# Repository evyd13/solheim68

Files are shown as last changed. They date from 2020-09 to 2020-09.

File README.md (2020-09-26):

# Solheim68

Solheim68 PCB
This PCB is a direct replacement designed for the VA68M (Mini-USB) from Varmilo. Use this PCB as you wish, the license allows commercial use.  
Unfortunately it was impossible to support PCB mounted stabilizers on this one.

## Features
- Compatible with QMK Firmware
- More layout support (only with custom plate)

## Supported layouts
Supported layouts of the Solheim68

## Building
If you feel like building a few of these PCBs yourself, go to the 'Releases' tab and download the latest gerber files. Order those at your favourite PCB manufacturer, get the components needed (see below) and solder them on! A hot air station is not required but a soldering iron is. Flux is recommended.

## Opening the project
To open the files you will need the latest KiCAD nightly version.

## Bill of materials (BOM)
Amount is per PCB, multiply as needed.

| LCSC part # | Description | Value | Package  | Amount |
| --- | --- | ----- | --- | ---:|
| C128353 | Capacitor | 0.1uF | 0805 | 4 |
| C131056 | Capacitor | 4.7uF | 0805 | 1 |
| C215803 | Capacitor | 1uF | 0805 | 1 |
| C109001 | Diode | | 0805 | 72 |
| C145778 | USB Connector | | SMD/THT  | 1 |
| C103904 | Resistor | 10K | 0805 | 2 |
| C325772 | Resistor | 22 | 0805 | 2 |
| C44854 | MCU | 32U4  | QFP-44 | 1 |
| C341521 | Resonator | 16MHz | SMD | 1 |
| C92584 | Switch | | SMD | 1 |

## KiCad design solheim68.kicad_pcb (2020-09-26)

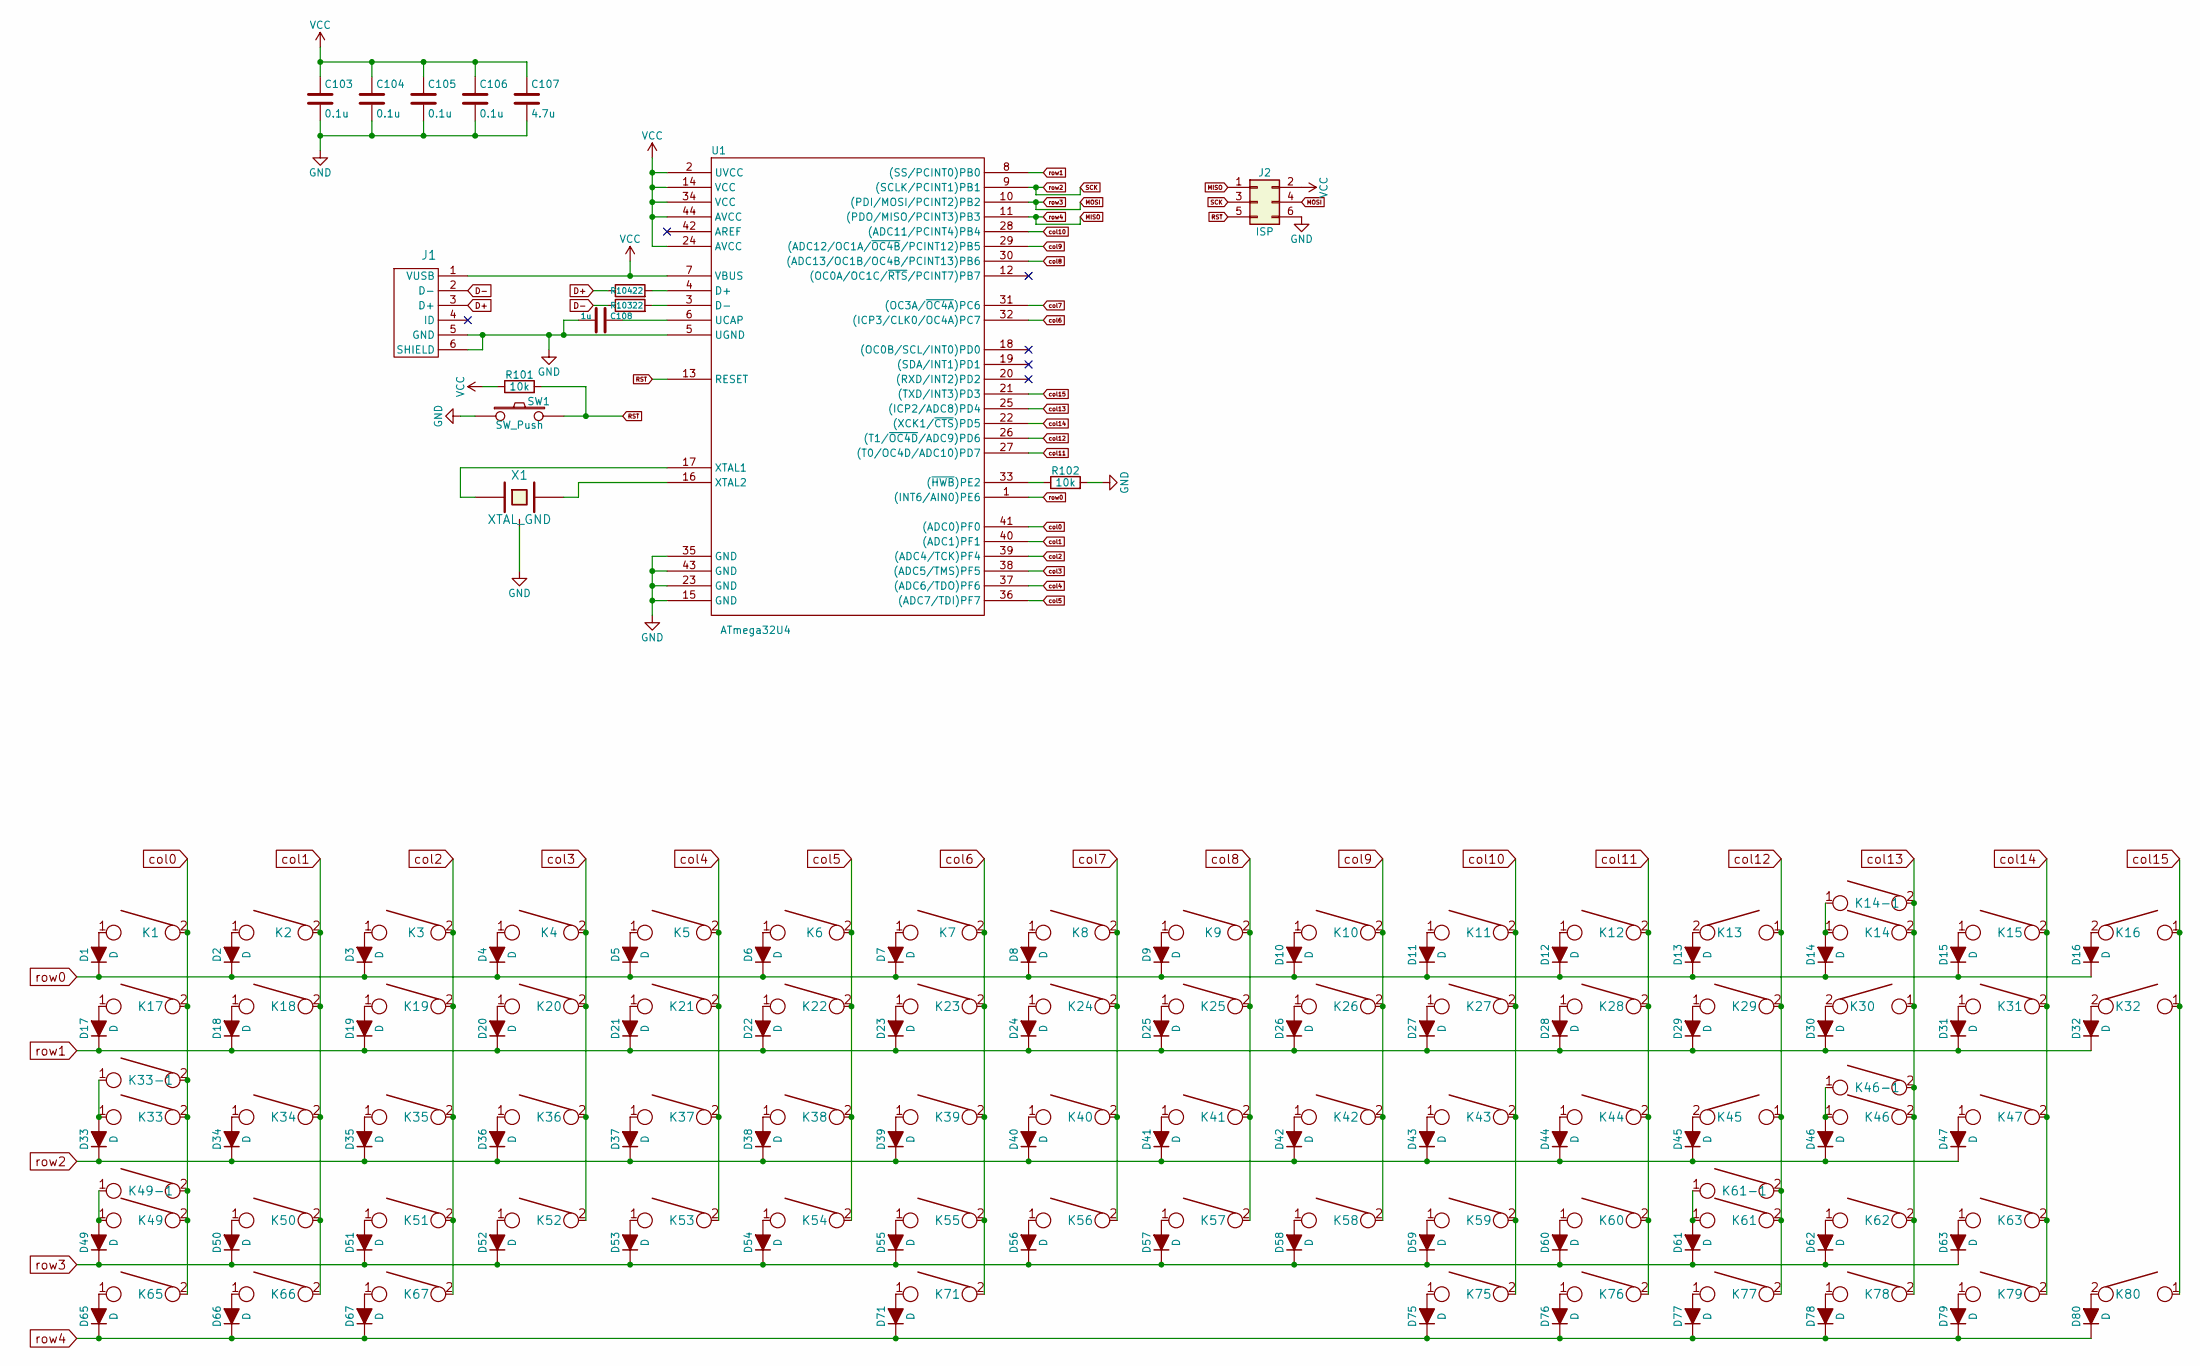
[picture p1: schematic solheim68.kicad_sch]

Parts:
C103, C104, C105, C106: 0.1u; C_0805
C107: 4.7u; C_0805
C108: 1u; C_0805
D1, D2, D3, D4, D5, D6, D7, D8, D9, D10, D11, D12, D13, D14, D15, D16, D17, D18, D19, D20, D21, D22, D23, D24, D25, D26, D27, D28, D29, D30, D31, D32, D33, D34, D35, D36, D37, D38, D39, D40, D41, D42, D43, D44, D45, D46, D47, D49, D50, D51, D52, D53, D54, D55, D56, D57, D58, D59, D60, D61, D62, D63, D65, D66, D67, D71, D75, D76, D77, D78, D79, D80: D; D_0805
J1: USB_mini_micro_B; U-M-M5DD-W-1
J2: ISP; isp_standard
K1, K2, K3, K4, K5, K6, K7, K8, K9, K10, K11, K12, K13, K14-1, K15, K16, K18, K19, K20, K21, K22, K23, K24, K25, K26, K27, K28, K29, K31, K32, K34, K35, K36, K37, K38, K39, K40, K41, K42, K43, K44, K45, K47, K50, K51, K52, K53, K54, K55, K56, K57, K58, K59, K60, K62, K63, K78, K79, K80: KEYSW; CHERRY_PLATE_100H
K14: KEYSW; CHERRY_PLATE_200H
K17, K30: KEYSW; CHERRY_PLATE_150H
K33, K61-1: KEYSW; CHERRY_PLATE_175H
K33-1, K49-1, K65, K66, K67, K75, K76, K77: KEYSW; CHERRY_PLATE_125H
K46, K49: KEYSW; CHERRY_PLATE_225H
K46-1: KEYSW; CHERRY_PLATE_200H_V
K61: KEYSW; CHERRY_PLATE_275H
K71: KEYSW; CHERRY_PLATE_625H
R101, R102: 10k; R_0805
R103, R104: 22; R_0805
SW1: SW_Push; SW_SPST_TL3342
U1: ATmega32U4; ATMEGA32U4
X1: XTAL_GND; Resonator_SMD_muRata_CSTNExxV-3Pin-p1.2

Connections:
D+: J1.3 (D+), R104.1
D-: J1.2 (D-), R103.1
GND: C103.2, C104.2, C105.2, C106.2, C107.2, C108.2, J1.5 (GND), J1.6 (SHIELD), J2.6, R102.2, SW1.1, U1.5 (UGND), U1.15 (GND), U1.23 (GND), U1.35 (GND), U1.43 (GND), X1.3
MISO: D65.1 (K), D66.1 (K), D67.1 (K), D71.1 (K), D75.1 (K), D76.1 (K), D77.1 (K), D78.1 (K), D79.1 (K), D80.1 (K), J2.1, U1.11 ((PDO/MISO/PCINT3)PB3)
MOSI: D49.1 (K), D50.1 (K), D51.1 (K), D52.1 (K), D53.1 (K), D54.1 (K), D55.1 (K), D56.1 (K), D57.1 (K), D58.1 (K), D59.1 (K), D60.1 (K), D61.1 (K), D62.1 (K), D63.1 (K), J2.4, U1.10 ((PDI/MOSI/PCINT2)PB2)
unnamed: C108.1, U1.6 (UCAP)
unnamed: D1.2 (A), K1.1
unnamed: D2.2 (A), K2.1
unnamed: D3.2 (A), K3.1
unnamed: D4.2 (A), K4.1
unnamed: D5.2 (A), K5.1
unnamed: D6.2 (A), K6.1
unnamed: D7.2 (A), K7.1
unnamed: D8.2 (A), K8.1
unnamed: D9.2 (A), K9.1
unnamed: D10.2 (A), K10.1
unnamed: D11.2 (A), K11.1
unnamed: D12.2 (A), K12.1
unnamed: D13.2 (A), K13.2
unnamed: D14.2 (A), K14.1, K14-1.1
unnamed: D15.2 (A), K15.1
unnamed: D16.2 (A), K16.2
unnamed: D17.2 (A), K17.1
unnamed: D18.2 (A), K18.1
unnamed: D19.2 (A), K19.1
unnamed: D20.2 (A), K20.1
unnamed: D21.2 (A), K21.1
unnamed: D22.2 (A), K22.1
unnamed: D23.2 (A), K23.1
unnamed: D24.2 (A), K24.1
unnamed: D25.2 (A), K25.1
unnamed: D26.2 (A), K26.1
unnamed: D27.2 (A), K27.1
unnamed: D28.2 (A), K28.1
unnamed: D29.2 (A), K29.1
unnamed: D30.2 (A), K30.2
unnamed: D31.2 (A), K31.1
unnamed: D32.2 (A), K32.2
unnamed: D33.2 (A), K33.1, K33-1.1
unnamed: D34.2 (A), K34.1
unnamed: D35.2 (A), K35.1
unnamed: D36.2 (A), K36.1
unnamed: D37.2 (A), K37.1
unnamed: D38.2 (A), K38.1
unnamed: D39.2 (A), K39.1
unnamed: D40.2 (A), K40.1
unnamed: D41.2 (A), K41.1
unnamed: D42.2 (A), K42.1
unnamed: D43.2 (A), K43.1
unnamed: D44.2 (A), K44.1
unnamed: D45.2 (A), K45.2
unnamed: D46.2 (A), K46.1, K46-1.1
unnamed: D47.2 (A), K47.1
unnamed: D49.2 (A), K49.1, K49-1.1
unnamed: D50.2 (A), K50.1
unnamed: D51.2 (A), K51.1
unnamed: D52.2 (A), K52.1
unnamed: D53.2 (A), K53.1
unnamed: D54.2 (A), K54.1
unnamed: D55.2 (A), K55.1
unnamed: D56.2 (A), K56.1
unnamed: D57.2 (A), K57.1
unnamed: D58.2 (A), K58.1
unnamed: D59.2 (A), K59.1
unnamed: D60.2 (A), K60.1
unnamed: D61.2 (A), K61.1, K61-1.1
unnamed: D62.2 (A), K62.1
unnamed: D63.2 (A), K63.1
unnamed: D65.2 (A), K65.1
unnamed: D66.2 (A), K66.1
unnamed: D67.2 (A), K67.1
unnamed: D71.2 (A), K71.1
unnamed: D75.2 (A), K75.1
unnamed: D76.2 (A), K76.1
unnamed: D77.2 (A), K77.1
unnamed: D78.2 (A), K78.1
unnamed: D79.2 (A), K79.1
unnamed: D80.2 (A), K80.2
unnamed: R102.1, U1.33 ((~HWB~)PE2)
unnamed: R103.2, U1.3 (D-)
unnamed: R104.2, U1.4 (D+)
unnamed: U1.16 (XTAL2), X1.2
unnamed: U1.17 (XTAL1), X1.1
RST: J2.5, R101.2, SW1.2, U1.13 (RESET)
SCK: D33.1 (K), D34.1 (K), D35.1 (K), D36.1 (K), D37.1 (K), D38.1 (K), D39.1 (K), D40.1 (K), D41.1 (K), D42.1 (K), D43.1 (K), D44.1 (K), D45.1 (K), D46.1 (K), D47.1 (K), J2.3, U1.9 ((SCLK/PCINT1)PB1)
VCC: C103.1, C104.1, C105.1, C106.1, C107.1, J1.1 (VUSB), J2.2, R101.1, U1.2 (UVCC), U1.7 (VBUS), U1.14 (VCC), U1.24 (AVCC), U1.34 (VCC), U1.44 (AVCC)
col0: K1.2, K17.2, K33.2, K33-1.2, K49.2, K49-1.2, K65.2, U1.41 ((ADC0)PF0)
col1: K2.2, K18.2, K34.2, K50.2, K66.2, U1.40 ((ADC1)PF1)
col2: K3.2, K19.2, K35.2, K51.2, K67.2, U1.39 ((ADC4/TCK)PF4)
col3: K4.2, K20.2, K36.2, K52.2, U1.38 ((ADC5/TMS)PF5)
col4: K5.2, K21.2, K37.2, K53.2, U1.37 ((ADC6/TDO)PF6)
col5: K6.2, K22.2, K38.2, K54.2, U1.36 ((ADC7/TDI)PF7)
col6: K7.2, K23.2, K39.2, K55.2, K71.2, U1.32 ((ICP3/CLK0/OC4A)PC7)
col7: K8.2, K24.2, K40.2, K56.2, U1.31 ((OC3A/~OC4A~)PC6)
col8: K9.2, K25.2, K41.2, K57.2, U1.30 ((ADC13/OC1B/OC4B/PCINT13)PB6)
col9: K10.2, K26.2, K42.2, K58.2, U1.29 ((ADC12/OC1A/~OC4B~/PCINT12)PB5)
col10: K11.2, K27.2, K43.2, K59.2, K75.2, U1.28 ((ADC11/PCINT4)PB4)
col11: K12.2, K28.2, K44.2, K60.2, K76.2, U1.27 ((T0/OC4D/ADC10)PD7)
col12: K13.1, K29.2, K45.1, K61.2, K61-1.2, K77.2, U1.26 ((T1/~OC4D~/ADC9)PD6)
col13: K14.2, K14-1.2, K30.1, K46.2, K46-1.2, K62.2, K78.2, U1.25 ((ICP2/ADC8)PD4)
col14: K15.2, K31.2, K47.2, K63.2, K79.2, U1.22 ((XCK1/~CTS~)PD5)
col15: K16.1, K32.1, K80.1, U1.21 ((TXD/INT3)PD3)
row0: D1.1 (K), D2.1 (K), D3.1 (K), D4.1 (K), D5.1 (K), D6.1 (K), D7.1 (K), D8.1 (K), D9.1 (K), D10.1 (K), D11.1 (K), D12.1 (K), D13.1 (K), D14.1 (K), D15.1 (K), D16.1 (K), U1.1 ((INT6/AIN0)PE6)
row1: D17.1 (K), D18.1 (K), D19.1 (K), D20.1 (K), D21.1 (K), D22.1 (K), D23.1 (K), D24.1 (K), D25.1 (K), D26.1 (K), D27.1 (K), D28.1 (K), D29.1 (K), D30.1 (K), D31.1 (K), D32.1 (K), U1.8 ((SS/PCINT0)PB0)

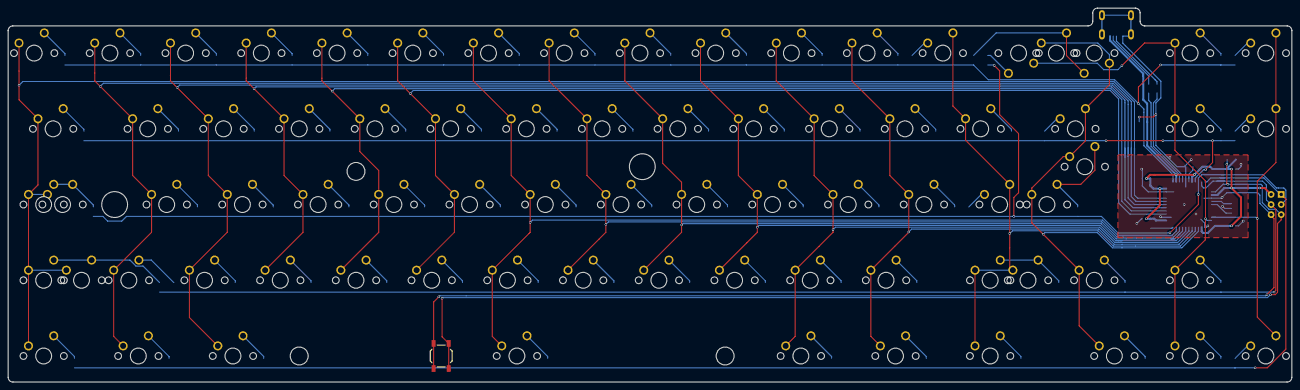
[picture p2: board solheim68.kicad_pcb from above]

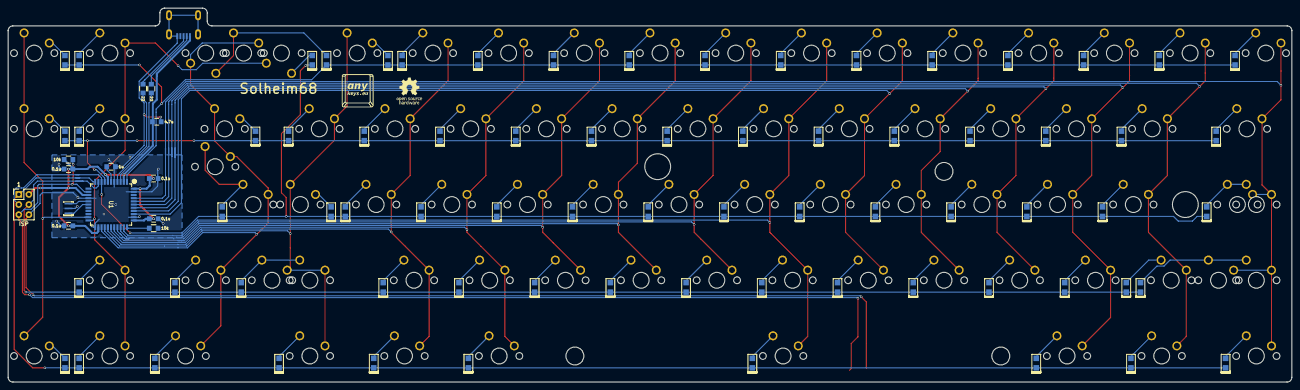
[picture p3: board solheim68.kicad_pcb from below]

Board: 2 copper layers, 323.0 x 94.1 mm, 164 parts (86 on the bottom side), 104 nets.

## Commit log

2020-08-28 Upload rev1 files
    [solheim68.kicad_pcb, solheim68.kicad_sch]
2020-09-26 Add website logo/remove maartenwut
    [solheim68.kicad_pcb]
